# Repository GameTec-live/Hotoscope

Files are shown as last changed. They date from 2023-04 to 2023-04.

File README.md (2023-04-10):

# Hotoscope
Hotoscope, Merge a hotplate and a microscope

The Hotoscope is a DIY hotplate combined with a cheap mircoscope and stand to do reflow/Hotplate soldering.

It Features 2 Defineable curves for Soldering and Desoldering, it also supports a Manual Temperature setting.

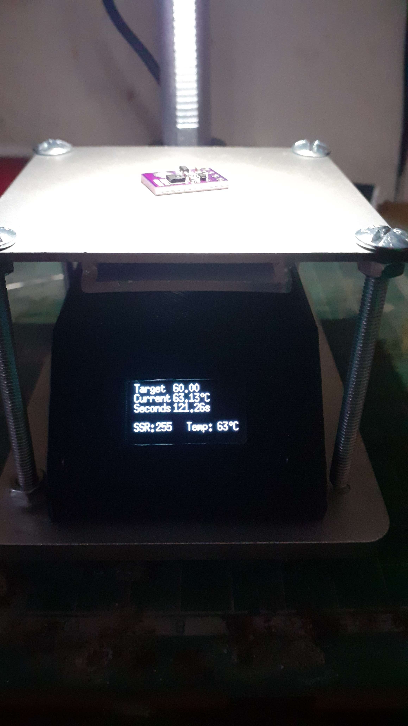
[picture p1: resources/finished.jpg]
Finished thing


## Guide

### Requirements
* Software:
    * [This Repository](https://github.com/GameTec-live/Hotoscope/archive/refs/heads/main.zip)
    * [VS Code](https://code.visualstudio.com/)
    * [PlatformIO](https://platformio.org/install/ide?install=vscode)
* Hardware:
    * [Arduino pro micro 328p pro mini or Clone (5V)](https://aliexpress.com/item/4000321145570.html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)
    * [SSR, 2AMP Rated for mains voltage](aliexpress.com/item/1005004650376762.html?pdp_npi=2%40dis%21GBP%21￡%200.98%21￡%200.69%21%21%21%21%21%40211b613916811404841866479ec512%2112000032063843810%21btf&_t=pvid:782a5978-c6d1-453b-b5dd-098ef49f97f2&afTraceInfo=1005004650376762__pc__pcBridgePPC__xxxxxx__1681140484&spm=a2g0o.ppclist.product.mainProduct)
    * [Mains to 5V PSU](https://www.ebay.co.uk/itm/255861034090?itemid=255861034090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)
    * [Termistor, b3950](https://www.ebay.co.uk/itm/191094757881?var=490279055890)
    * [Passive buzzer 9mmx6mm](https://www.alibaba.com/product-detail/Small-MANORSHI-small-12mm-pitch-6_1600509940899.html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)
    * [4 5x5x9mm Buttons](https://www.futureelectronics.com/p/electromechanical--switches--tactile/1-1825910-4-te-connectivity-3151637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)
    * [Oled Screen ssd1306 i2c](https://www.ebay.co.uk/itm/191094757881?var=490279055890)
    * [Hotplate](https://www.aliexpress.com/item/1005004388602432.html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)
    * [Stand](https://www.aliexpress.com/item/1005003345032593.html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)
    * [Microscope](https://www.aliexpress.com/item/1005005302044086.html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)
    * USB TTL Converter for programming
    * 2.2k resistor
    * 10uf Capacitor
    * 4 50mm m4 nuts and bolts
    * (Optional) 2 10k resistors for the i2c lines
    * [(Optional) 3D Printed Case](https://github.com/GameTec-live/Hotoscope/tree/main/resources)

### Hardware
Connect the components according to the following diagram:
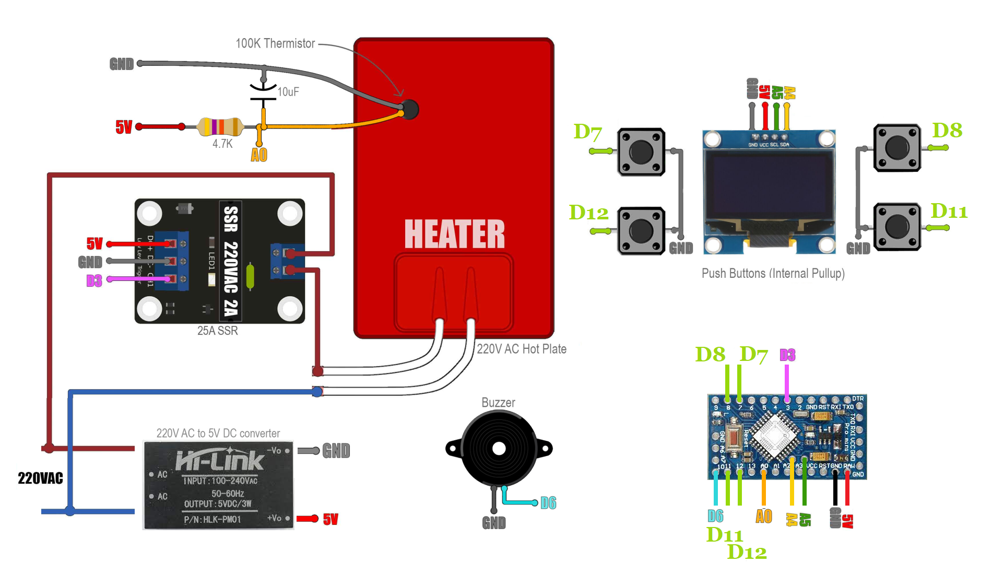
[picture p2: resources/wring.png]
Wiring Diagram


To secure it to the housing you may use a glue of your choice.

### Software
Download install VS Code and PlatformIO, also Download this repository and unpack it into a folder of you choosing.
After the Downloads are Complete, Open VS Code and go to File -> Open Folder... and choose the folder you unpacked this Repository into.
PlatformIO should let you know, that it is a PlatformIO project by popping up PlatformIO Home and platformio.ini. Close and ignore those.
Connect your arduino to your pc, click on the alien (PlatformIO) in VS Codes sidebar and Press "Upload". Done, PlatformIO will do the rest and thats the software part.
<details>
    <summary>Advanced Configuration</summary>
    Lets say you cant get your hands on a Pro Mini, you can change for what processor PIO builds by modifying lines 11 and 13 in platformio.ini (Refer to PIO Docs for more info)
    Lets say you want to customize your Curves. Open main.cpp and look at lines 18 - 28. Those lines are the solder and desolder curves.
    the left side defines at what second it switches to the next stage, the right side is the temperature in °C.
    Adjust those Curvse according to your needs.

    NOTE: Depending on your Hotplate and Heating Pad you may need to fiddle around with the PID values.
</details>

## Usage
Now that you have your Hotoscope, lets go over how to use it:

When starting up you will be greeted with the main menu. At the bottom you find the current SSR dutycycle and current Temperature sensors.
You navigate the menu by pressing the right button (right top -> up, right bottom -> down)
You Select the entry by pressing the bottom left button. This button acts as a "back" button in any Menu not the main Menu. Hold this button for a while and you will be greeted with a shortcut to manual mode.
The top left buttons is a shortcut to solder mode and immidately starts the Soldering cycle.

In Manual mode (either selected from the menu or long press) you set the temperature via the up and down buttons.

In Solder mode (Menu or shortcut button) the temperature follows the predetermined curve.

In Desolder mode its the same as solder mode.

Cooldown just sets everything to 0 and cools down.

And thats all there is to it :p

Have fun soldering, youll figure it out!

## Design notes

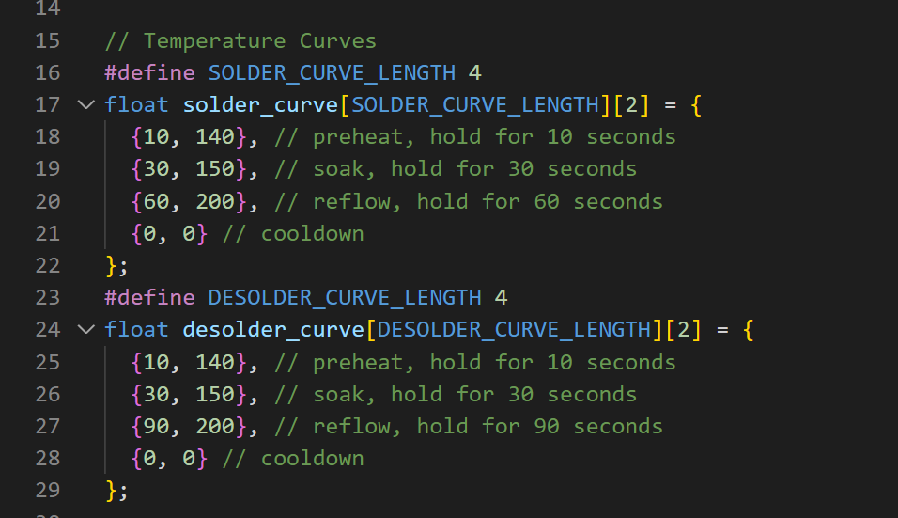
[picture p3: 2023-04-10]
resources/curves.png

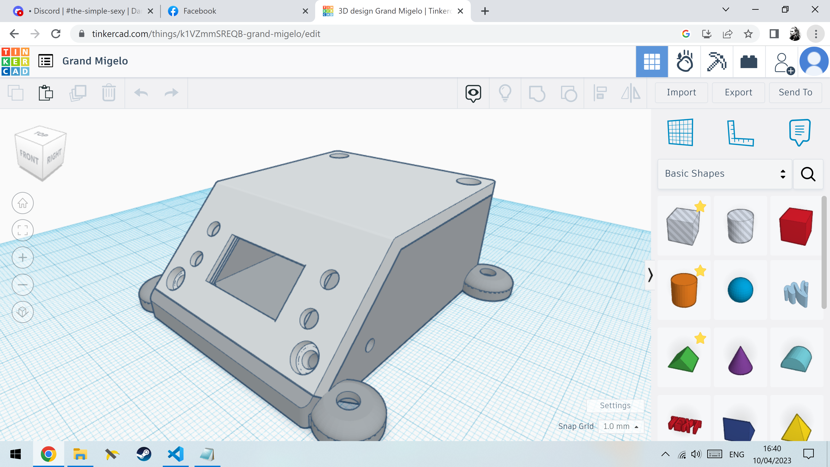
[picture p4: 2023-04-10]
resources/3dmodel.png

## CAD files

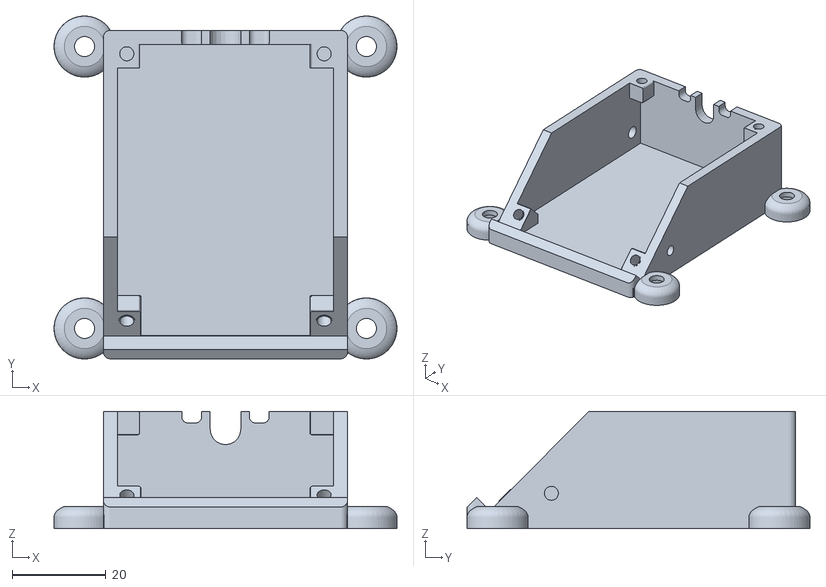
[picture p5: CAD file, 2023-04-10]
resources/hotscope_base_stl.stl
73.0 x 73.0 x 25.0

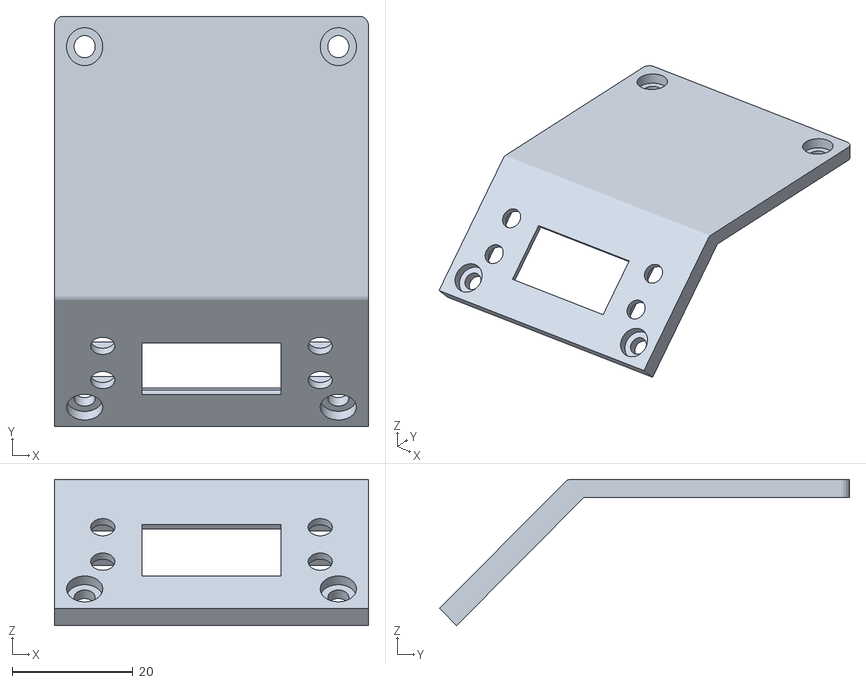
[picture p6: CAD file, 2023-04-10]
resources/hotscope_lid_stl.stl
52.0 x 67.9 x 24.2

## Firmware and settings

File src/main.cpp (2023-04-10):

#include <Arduino.h>

// Thermistor
#include <Thermistor.h>
#include <NTC_Thermistor.h>

#define SENSOR_PIN             A0
#define REFERENCE_RESISTANCE   2200
#define NOMINAL_RESISTANCE     100000
#define NOMINAL_TEMPERATURE    25
#define B_VALUE                3950
Thermistor* thermistor;
static double celsius = 0;

// Temperature Curves
#define SOLDER_CURVE_LENGTH 4
float solder_curve[SOLDER_CURVE_LENGTH][2] = {
  {10, 140}, // preheat, hold for 10 seconds
  {30, 150}, // soak, hold for 30 seconds
  {60, 200}, // reflow, hold for 60 seconds
  {0, 0} // cooldown
};
#define DESOLDER_CURVE_LENGTH 4
float desolder_curve[DESOLDER_CURVE_LENGTH][2] = {
  {10, 140}, // preheat, hold for 10 seconds
  {30, 150}, // soak, hold for 30 seconds
  {90, 200}, // reflow, hold for 90 seconds
  {0, 0} // cooldown
};

// PID
float Kp = 2;
float Ki = 0.0025;
float Kd = 9;
float PID_Output = 0;
float PID_P, PID_I, PID_D;
float PID_ERROR, PREV_ERROR;
float MIN_PID_VALUE = 0;
float MAX_PID_VALUE = 180;

// Buttons
int but_1 = 12; // (top left - Solder Cycle shortcut)
int but_2 = 7; // (bottom left - Manual Heating shortcut / select)
int but_3 = 11; // (top right - up)
int but_4 = 8; // (bottom right - down)

// other
int SSR = 3;
int buzzer = 10;

// Screen
#include <Wire.h>
#include <U8g2lib.h>
U8G2_SSD1306_128X64_NONAME_F_HW_I2C u8g2(U8G2_R2, /* reset=*/ U8X8_PIN_NONE);

// Variables
int current_menu = 0; // 0 = main menu, 1 = solder, 2 = desolder, 3 = manual, 4 = cooldown (skippable)
int slctd = 0; // selected menu item
unsigned int millis_before, millis_before_2; // for refresh rate limiting+
unsigned int millis_now = 0;
float refresh_rate = 60; // Oled refresh rate in ms
float pid_refresh_rate  = 50; // PID refresh rate in ms
float seconds = 0; // for time keeping
float pwm_value = 255; // SSR is off with 255
float cooldown_temp = 40; // temperature to cool down to / safe to touch plate
float setpoint = 0; // temperature to reach

// Functions
void mainmenu(int selection);
int input_handler();
void menu_handler();
void PID(double setpoint, double current_temp);
void cooldownmenu(int selection);
void soldermenu(int selection);

// logo
const unsigned char bitmap_7va4yl[] PROGMEM = {
  0x00,0x00,0x00,0x00,0x00,0x00,0x00,0x00,0x00,0x00,0x00,0x00,0x00,0x00,0x00,0x00,
  0x00,0x00,0x00,0x00,0x00,0x00,0x00,0x00,0x00,0x00,0x00,0x00,0x00,0x00,0x00,0x00,
  0x00,0x00,0x00,0x00,0x00,0x00,0x00,0x00,0x00,0x00,0x00,0x00,0x00,0x00,0x00,0x00,
  0x00,0x00,0x00,0x00,0x00,0x00,0x00,0x00,0x00,0x00,0x00,0x00,0x00,0x00,0x00,0x00,
  0x00,0x00,0x00,0x00,0x00,0x00,0x00,0x00,0x00,0x00,0x00,0x00,0x00,0x00,0x00,0x00,
  0x00,0x00,0x00,0x00,0x00,0x00,0x00,0x00,0x00,0x00,0x00,0x00,0x00,0x00,0x00,0x00,
  0x00,0x00,0x00,0x00,0x00,0x00,0x00,0x00,0x00,0x00,0x00,0x00,0x00,0x00,0x00,0x00,
  0x00,0x00,0x00,0x00,0x00,0x00,0x00,0x00,0x00,0x00,0x00,0x00,0x00,0x00,0x00,0x00,
  0x00,0x00,0x00,0x00,0x00,0x00,0x1C,0x00,0x00,0x00,0x00,0x00,0x00,0x00,0x00,0x00,
  0x00,0x00,0x00,0x00,0x00,0x00,0x1C,0x00,0x00,0x00,0x00,0x00,0x00,0x00,0x00,0x00,
  0x00,0x00,0x00,0x00,0x00,0x00,0x1C,0x18,0x00,0x00,0x00,0x00,0x00,0x00,0x00,0x00,
  0x00,0x00,0x00,0x00,0x00,0x00,0x1C,0x18,0x00,0x00,0x00,0x00,0x00,0x00,0x00,0x00,
  0x00,0x00,0x00,0x00,0x00,0x00,0x3F,0xFC,0x00,0x00,0x00,0x00,0x00,0x00,0x00,0x00,
  0x00,0x00,0x00,0x00,0x00,0x00,0x3F,0xFC,0x00,0x00,0x00,0x00,0x00,0x00,0x00,0x00,
  0x00,0x00,0x00,0x00,0x00,0x00,0x1C,0x18,0x00,0x00,0x00,0x00,0x00,0x00,0x00,0x00,
  0x00,0x00,0x00,0x00,0x00,0x00,0x1C,0x18,0x00,0x00,0x00,0x00,0x00,0x00,0x00,0x00,
  0x00,0x00,0x00,0x00,0x00,0x00,0x1C,0x18,0x00,0x00,0x00,0x00,0x00,0x00,0x00,0x00,
  0x00,0x00,0x00,0x00,0x00,0x00,0x1C,0x00,0x00,0x00,0x00,0x00,0x00,0x00,0x00,0x00,
  0x00,0x00,0x00,0x00,0x00,0x00,0x1C,0x00,0x00,0x00,0x00,0x00,0x00,0x00,0x00,0x00,
  0x00,0x00,0x00,0x00,0x00,0x00,0x1C,0x00,0x00,0x00,0x00,0x00,0x00,0x00,0x00,0x00,
  0x00,0x00,0x00,0x00,0x00,0x00,0x1C,0x00,0x00,0x00,0x00,0x00,0x00,0x00,0x00,0x00,
  0x00,0x00,0x00,0x00,0x00,0x00,0x1C,0x00,0x00,0x00,0x00,0x00,0x00,0x00,0x00,0x00,
  0x00,0x00,0x00,0x00,0x00,0x00,0x1C,0x00,0x00,0x00,0x00,0x00,0x00,0x00,0x00,0x00,
  0x00,0x00,0x00,0x00,0x00,0x00,0x1C,0x00,0x00,0x00,0x00,0x00,0x00,0x00,0x00,0x00,
  0x00,0x00,0x00,0x00,0x00,0x00,0x1C,0x00,0x00,0x00,0x00,0x00,0x00,0x00,0x00,0x00,
  0x00,0x00,0x00,0x00,0x00,0x00,0x1C,0x7E,0x00,0x00,0x00,0x00,0x00,0x00,0x00,0x00,
  0x00,0x00,0x00,0x00,0x00,0x00,0x1C,0x7E,0x00,0x00,0x00,0x00,0x00,0x00,0x00,0x00,
  0x00,0x00,0x00,0x00,0x00,0x00,0x1C,0x7F,0x00,0x00,0x00,0x00,0x00,0x00,0x00,0x00,
  0x00,0x00,0x00,0x00,0x00,0x01,0xFF,0xFF,0x80,0x00,0x00,0x00,0x00,0x00,0x00,0x00,
  0x00,0x00,0x00,0x00,0x00,0x01,0xFF,0xFF,0x80,0x00,0x00,0x00,0x00,0x00,0x00,0x00,
  0x00,0x00,0x00,0x00,0x00,0x00,0x00,0x00,0x00,0x00,0x00,0x00,0x00,0x00,0x00,0x00,
  0x00,0x00,0x00,0x00,0x00,0x00,0x00,0x00,0x00,0x00,0x00,0x00,0x00,0x00,0x00,0x00,
  0x00,0x00,0x00,0x00,0x00,0x00,0x00,0x00,0x00,0x00,0x00,0x00,0x00,0x00,0x00,0x00,
  0x00,0x00,0x00,0x00,0x00,0x00,0x00,0x00,0x00,0x00,0x00,0x00,0x00,0x00,0x00,0x00,
  0x00,0x00,0x00,0x00,0x00,0x00,0x00,0x00,0x00,0x00,0x00,0x00,0x00,0x00,0x00,0x00,
  0x00,0x00,0x00,0x00,0x00,0x00,0x00,0x00,0x00,0x00,0x00,0x00,0x00,0x00,0x00,0x00,
  0x00,0x00,0x00,0x00,0x00,0x00,0x00,0x00,0x00,0x00,0x00,0x00,0x00,0x00,0x00,0x00,
  0x00,0x00,0x00,0x00,0x00,0x00,0x00,0x00,0x00,0x00,0x00,0x00,0x00,0x00,0x00,0x00,
  0x00,0x00,0x00,0x00,0x00,0x00,0x00,0x00,0x00,0x00,0x00,0x00,0x00,0x00,0x00,0x00,
  0x00,0x07,0xF9,0xFC,0x00,0x00,0x00,0x00,0x00,0x00,0x00,0x00,0x00,0x00,0x00,0x00,
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
};


void setup() {
  // Setup Thermistor
  thermistor = new NTC_Thermistor(
    SENSOR_PIN,
    REFERENCE_RESISTANCE,
    NOMINAL_RESISTANCE,
    NOMINAL_TEMPERATURE,
    B_VALUE
  );

  // Setup Buttons
  pinMode(but_1, INPUT_PULLUP);
  pinMode(but_2, INPUT_PULLUP);
  pinMode(but_3, INPUT_PULLUP);
  pinMode(but_4, INPUT_PULLUP);

  // Setup SSR
  pinMode(SSR, OUTPUT);
  digitalWrite(SSR, HIGH); // SSR off

  // Setup Buzzer
  pinMode(buzzer, OUTPUT);

  // Setup Screen
  u8g2.begin();
  u8g2.setFont(u8g2_font_6x13_tf);
  u8g2.enableUTF8Print();

  // Startup Screen
  u8g2.clearBuffer();
  u8g2.drawXBMP(0,0,128,64,bitmap_7va4yl);
  //u8g2.drawStr(32,26,"Hotoscope");
  u8g2.sendBuffer();
  delay(1000);
  tone(buzzer, 1800, 200); // Happy startup beep
  celsius = thermistor->readCelsius();
}

void loop() {
  // PID
  millis_now = millis();
  if(millis_now - millis_before_2 > pid_refresh_rate)
  {
    millis_before_2 = millis();
    celsius = thermistor->readCelsius();

    switch (current_menu)
    {
      case 1: // Solder
        for (int i = 0; i < SOLDER_CURVE_LENGTH; i++) {
          PID(solder_curve[i][1], celsius);
          if (seconds >= solder_curve[i][0]) {
            break;
          }
        }
        break;
      case 2: // Desolder
        for (int i = 0; i < DESOLDER_CURVE_LENGTH; i++) {
          PID(desolder_curve[i][1], celsius);
          if (seconds >= desolder_curve[i][0]) {
            break;
          }
        }
        break;
      case 3: // Manual
        PID(setpoint, celsius);
        break;
      case 4: // Cooldown
        PID(0, celsius);
        if (celsius <= cooldown_temp) {
          current_menu = 0;
        }
        seconds = 0;
        break;
      default:
        break;
    }
  }

  // OLED Handling
  millis_now = millis();
  if(millis_now - millis_before > refresh_rate) // refresh rate limiting
  {
    millis_before = millis();   
    seconds = seconds + (refresh_rate/1000); // time keeping
    menu_handler();
  }
}

void mainmenu(int selection) {
  u8g2.clearBuffer();
  if (selection == 0) {
    u8g2.drawStr(5,10,"Solder <-");
  }
  else {
    u8g2.drawStr(5,10,"Solder");
  }
  
  if (selection == 1) {
    u8g2.drawStr(5,21,"Desolder <-");
  }
  else {
    u8g2.drawStr(5,21,"Desolder");
  }

  if (selection == 2) {
    u8g2.drawStr(5,32,"Manual <-");
  }
  else {
    u8g2.drawStr(5,32,"Manual");
  }
  if (selection == 3) {
    u8g2.drawStr(5,43,"Cooldown <-");
  }
  else {
    u8g2.drawStr(5,43,"Cooldown");
  }
  // status
  u8g2.drawStr(5,53,"SSR:");
  u8g2.setCursor(30, 53);
  u8g2.print((int)pwm_value);
  u8g2.drawStr(65,53,"Temp:");
  u8g2.setCursor(100, 53);
  u8g2.print((int)celsius);
  u8g2.print("°C");
  u8g2.sendBuffer();
}

int input_handler() {
  int input = 0;
  if(digitalRead(but_1) == LOW) {
    input = 1;
  }
  if(digitalRead(but_2) == LOW) {
    input = 2;
  }
  if(digitalRead(but_3) == LOW) {
    input = 3;
  }
  if(digitalRead(but_4) == LOW) {
    input = 4;
  }
  // read in double press of button 2
  if(input == 2) {
    delay(500);
    if(digitalRead(but_2) == LOW) {
      input = 5;
      tone(buzzer, 1800, 200);
    }
  }
  return input;
}

void menu_handler() {
  int inpt = input_handler();
  switch (inpt)
  {
  case 1:
    // Solder Cycle shortcut
    current_menu = 1;
    break;
  case 2:
    // select
    if (current_menu == 0) {
      switch (slctd)
      {
      case 0:
        // Solder
        current_menu = 1;
        break;
      case 1:
        // Desolder
        current_menu = 2;
        break;
      case 2:
        // Manual
        current_menu = 3;
        break;
      case 3:
        // Cooldown
        current_menu = 4;
        break;
      default:
        break;
      }
      tone(buzzer, 1800, 200); // confirm beep
    }
    else 
    {
      current_menu = 0; // abort / back
      tone(buzzer, 1800, 200); // confirm beep
    }
    break;
  case 3:
    // up
    if (slctd < 2 && current_menu == 0) {
      slctd++;
    }
    if (current_menu == 3) {
      setpoint = setpoint - 5;
    }
    break;
  case 4:
    // down
    if (slctd > 0 && current_menu == 0) {
      slctd--;
    }
    if (current_menu == 3) {
      setpoint = setpoint + 5;
    }
    break;
  case 5:
    // Manual Heating shortcut
    current_menu = 3;
    tone(buzzer, 1800, 200); // confirm beep
    break;
  default:
    break;
  }

  switch (current_menu)
  {
  case 0:
    // Main Menu
    mainmenu(slctd);
    break;
  case 1:
    // Solder
    soldermenu(slctd);
    break;
  case 2:
    // Desolder
    soldermenu(slctd);
    break;
  case 3:
    // Manual
    soldermenu(slctd);
    break;
  case 4:
    // Cooldown
    cooldownmenu(slctd);
    break;
  default:
    break;
  }
}

void PID(double setpoint, double current_temp)
{       
  //Calculate PID
  PID_ERROR = setpoint - current_temp;
  PID_P = Kp*PID_ERROR;
  PID_I = PID_I+(Ki*PID_ERROR);      
  PID_D = Kd * (PID_ERROR-PREV_ERROR);
  PID_Output = PID_P + PID_I + PID_D;

  //Define maximun PID values
  if(PID_Output > MAX_PID_VALUE){
    PID_Output = MAX_PID_VALUE;
  }
  else if (PID_Output < MIN_PID_VALUE){
    PID_Output = MIN_PID_VALUE;
  }

  //Since the SSR is ON with LOW, we invert the pwm singal
  pwm_value = 255 - PID_Output; 
  analogWrite(SSR,pwm_value); //We change the Duty Cycle applied to the SSR
  
  PREV_ERROR = PID_ERROR;
}

void soldermenu(int selection) {
  u8g2.clearBuffer();
  u8g2.drawStr(5,10,"Target");
  u8g2.setCursor(50, 10);
  u8g2.print(setpoint);
  u8g2.drawStr(5,21,"Current");
  u8g2.setCursor(50, 21);
  u8g2.print(celsius);
  u8g2.print("°C");
  u8g2.drawStr(5,32,"Seconds");
  u8g2.setCursor(50, 32);
  u8g2.print(seconds);
  u8g2.print("s");

  // status
  u8g2.drawStr(5,53,"SSR:");
  u8g2.setCursor(30, 53);
  u8g2.print((int)pwm_value);
  u8g2.drawStr(65,53,"Temp:");
  u8g2.setCursor(100, 53);
  u8g2.print((int)celsius);
  u8g2.print("°C");
  u8g2.sendBuffer();
}

void cooldownmenu(int selection) {
  u8g2.clearBuffer();
  u8g2.drawStr(28,26,"Cooling down");

  // status
  u8g2.drawStr(5,53,"SSR:");
  u8g2.setCursor(30, 53);
  u8g2.print((int)pwm_value);
  u8g2.drawStr(65,53,"Temp:");
  u8g2.setCursor(100, 53);
  u8g2.print((int)celsius);
  u8g2.print("°C");
  u8g2.sendBuffer();
}

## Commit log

2023-04-09 added back screen, changed resistance
2023-04-10 moved temp read, hpfly fixed runetime error
    [main.cpp]
2023-04-10 fixed bugs, ui to arrows
    [main.cpp]
2023-04-10 removed oled / button cooldown
2023-04-10 added resources, deleted old
    [hotscope_base_stl.stl, hotscope_lid_stl.stl]
